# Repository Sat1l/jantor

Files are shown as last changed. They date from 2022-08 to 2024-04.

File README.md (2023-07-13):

# Jantor
Jantor
Jantor is a split-ergo-keyboard which derives its features from other ergo keebs: [Jian](https://github.com/KGOH/Jian-Info) (extra pinky keys), [Nijuni](https://github.com/krikun98/nijuni) (copied controller footprint) and [Cantor](https://github.com/diepala/cantor) (diodeless design with a Blackpill)

## Features
* Diodeless
* <30 min assembly time
* Combined MX and Hotswap footprints
* Fully simmetrical PCB
* Two ways to connect the halves: jumper wires and TRRS

## Case
EVA case
Current case design is designed to be cut out of EVA foam on a CNC laser and stacked together using EVA melting chemicals or instant glue.

Case .svg files are stored in the `case` folder, with folder `case production` having production optimised versions which have more pieces per sheet.

Raw case files are stored in `case kicad` folder in kicad project file format.

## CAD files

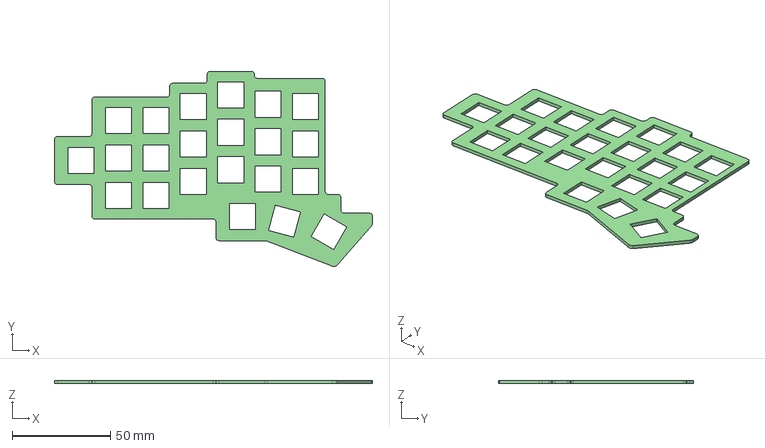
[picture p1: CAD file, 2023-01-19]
3ds/jantor plate.step
161.5 x 99.1 x 1.60 mm

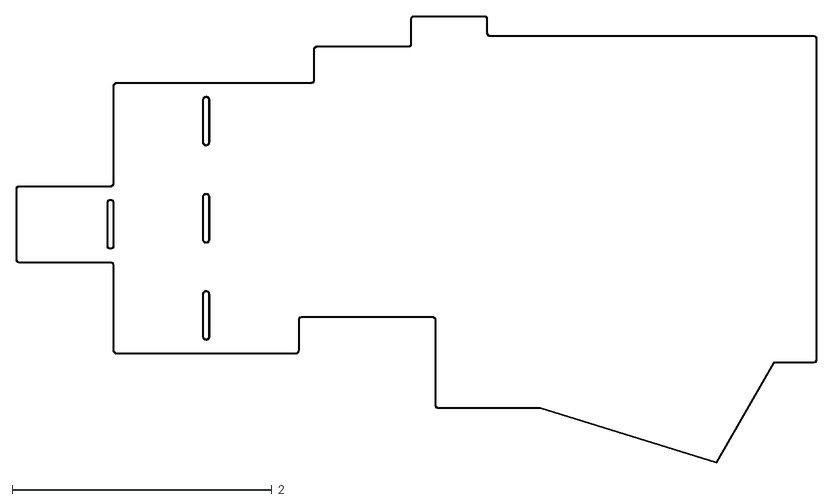
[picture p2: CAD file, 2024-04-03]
gerber/jantor-Edge_Cuts.dxf
6.16 x 3.44

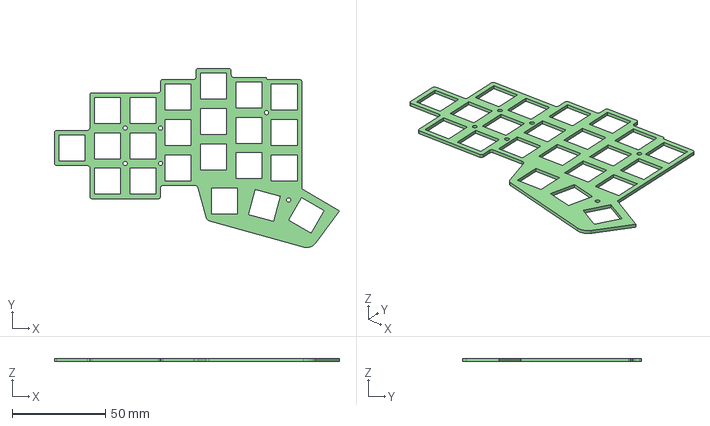
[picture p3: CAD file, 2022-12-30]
jantor plate/jantor.step
153.2 x 96.3 x 1.60 mm

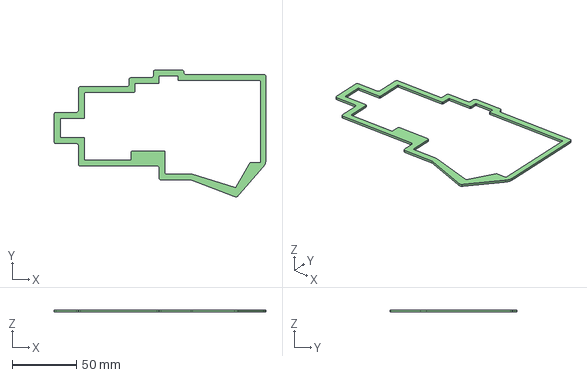
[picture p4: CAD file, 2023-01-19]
3ds/jantor midlayer.step
165.5 x 99.1 x 1.60 mm

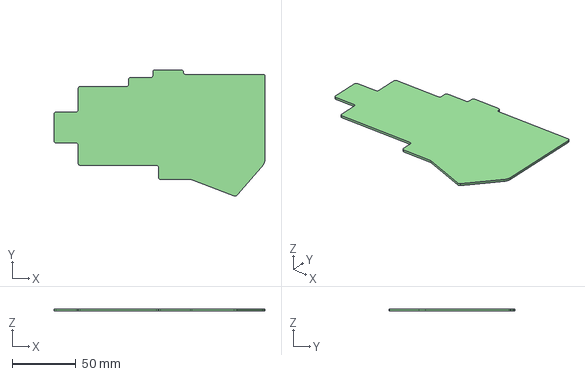
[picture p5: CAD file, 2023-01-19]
3ds/jantor bottom.step
165.5 x 99.1 x 1.60 mm

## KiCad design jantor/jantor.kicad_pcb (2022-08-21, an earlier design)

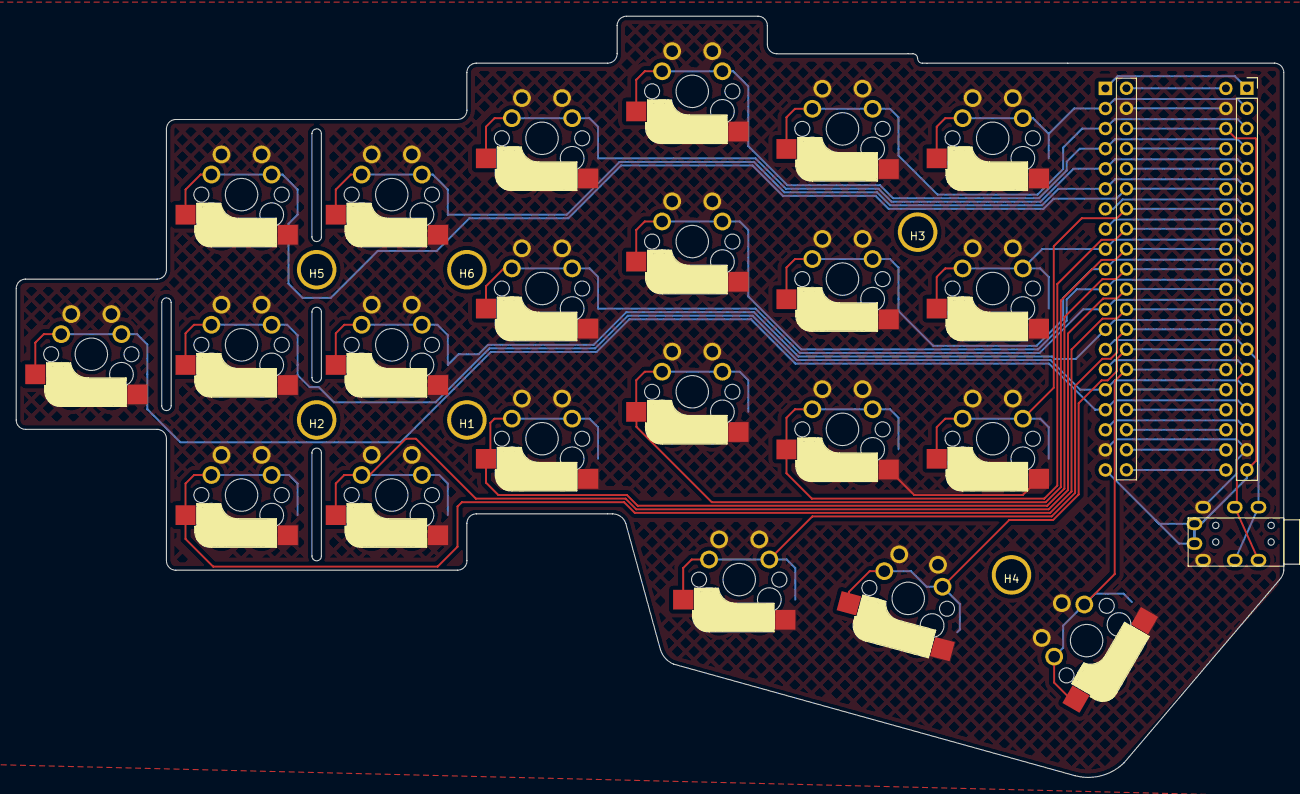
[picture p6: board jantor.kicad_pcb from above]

Board: 2 copper layers, 160.3 x 96.3 mm, 34 parts (0 on the bottom side), 26 nets.

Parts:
B1, B3, B4: breakaway; breakaway .75U (for 19mm net)
B2: breakaway; breakaway .5U (for 19mm net)
H1, H2, H3, H4, H5, H6: MountingHole; M2_Hole_TH_Outside
K00, K01, K02, K03, K04, K05, K10, K11, K12, K13, K14, K15, K16, K20, K21, K22, K23, K24, K25, K30, K31: KEYSW; MXOnly-1U-Hotswap-Optional-Reversible-19mm
K32: KEYSW; MXOnly-1.5U-Hotswap-Optional-Reversible-19mm
U1: YAAJ_WeAct_BlackPill_Part_Like; YAAJ_WeAct_BlackPill_2
U2: TRRS; TRRS-PJ-320A-Reversible

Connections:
+3V3: U1.20 (3V3), U1.38 (3V3), U2.1 (SLEEVE)
/RX: U1.15 (PB7), U2.3 (RING1)
/TX: U1.14 (PB6), U2.4 (RING2)
/k00: K00.1, U1.35 (PB1)
/k01: K01.1, U1.6 (PA9)
/k02: K02.1, U1.5 (PA8)
/k03: K03.1, U1.4 (PB15)
/k04: K04.1, U1.3 (PB14)
/k05: K05.1, U1.2 (PB13)
/k10: K10.1, U1.17 (PB9)
/k11: K11.1, U1.16 (PB8)
/k12: K12.1, U1.13 (PB5)
/k13: K13.1, U1.12 (PB4)
/k14: K14.1, U1.11 (PB3)
/k15: K15.1, U1.10 (PA15)
/k16: K16.1, U1.9 (PA12)
/k20: K20.1, U1.29 (PA3)
/k21: K21.1, U1.30 (PA4)
/k22: K22.1, U1.31 (PA5)
/k23: K23.1, U1.32 (PA6)
/k24: K24.1, U1.33 (PA7)
/k25: K25.1, U1.34 (PB0)
/k30: K30.1, U1.28 (PA2)
/k31: K31.1, U1.27 (PA1)
/k32: K32.1, U1.26 (PA0)
GND: K00.2, K01.2, K02.2, K03.2, K04.2, K05.2, K10.2, K11.2, K12.2, K13.2, K14.2, K15.2, K16.2, K20.2, K21.2, K22.2, K23.2, K24.2, K25.2, K30.2, K31.2, K32.2, U1.19 (GND), U1.39 (GND), U2.2 (TIP)

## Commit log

2022-08-20 initial commit
    no wiring and edges
    [jantor.kicad_pcb, jantor.kicad_sch]
2022-12-30 what i did like whaaaa
    [jantor-Edge_Cuts.dxf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]
2023-06-30 proto v0.?
    Completely new pcb and a new foam case. I'm currently typing this on an assembled board.
2024-04-03 hehehe i dont remember ANYTHING
    [jantor-Edge_Cuts.dxf, jantor.kicad_pcb, jantor.kicad_sch]
